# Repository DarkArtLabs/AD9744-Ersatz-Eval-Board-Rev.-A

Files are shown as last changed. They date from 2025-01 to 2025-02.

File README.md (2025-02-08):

# AD9744 Ersatz Eval Board
A low-cost evaluation board for the Analog Devices [AD9744](https://www.analog.com/en/products/ad9744.html) 14-bit DAC.

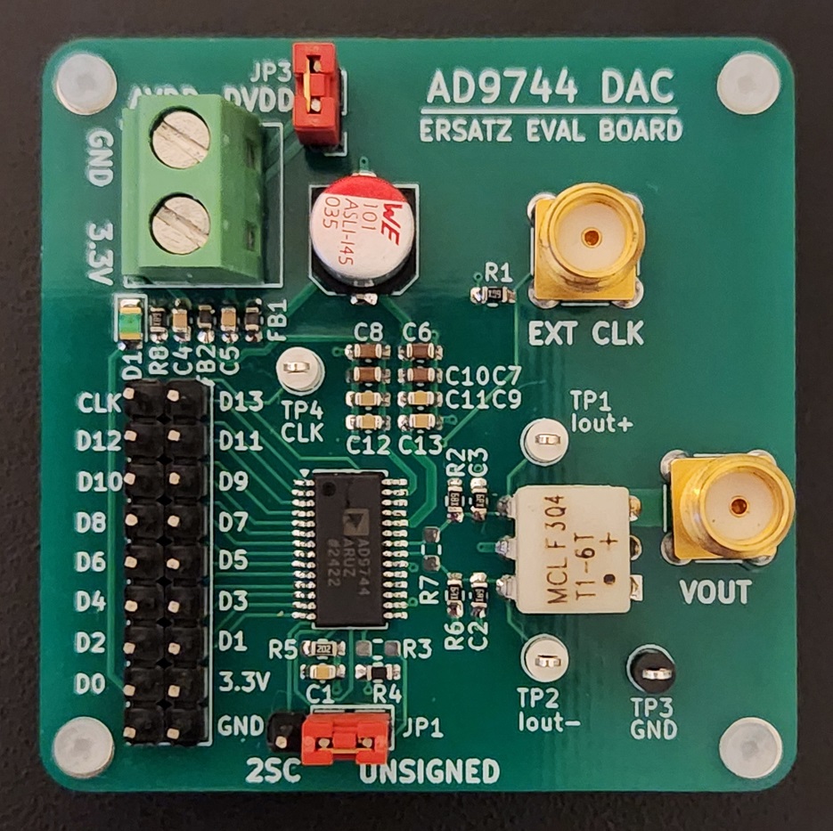
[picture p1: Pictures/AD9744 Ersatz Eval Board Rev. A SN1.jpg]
SN1


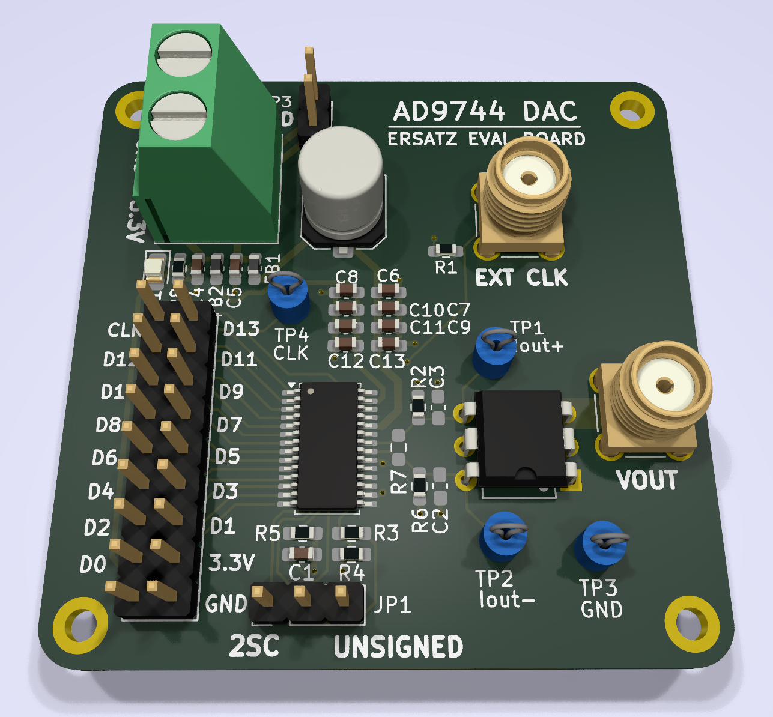
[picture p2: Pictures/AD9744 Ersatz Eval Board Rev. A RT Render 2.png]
3D Render Front


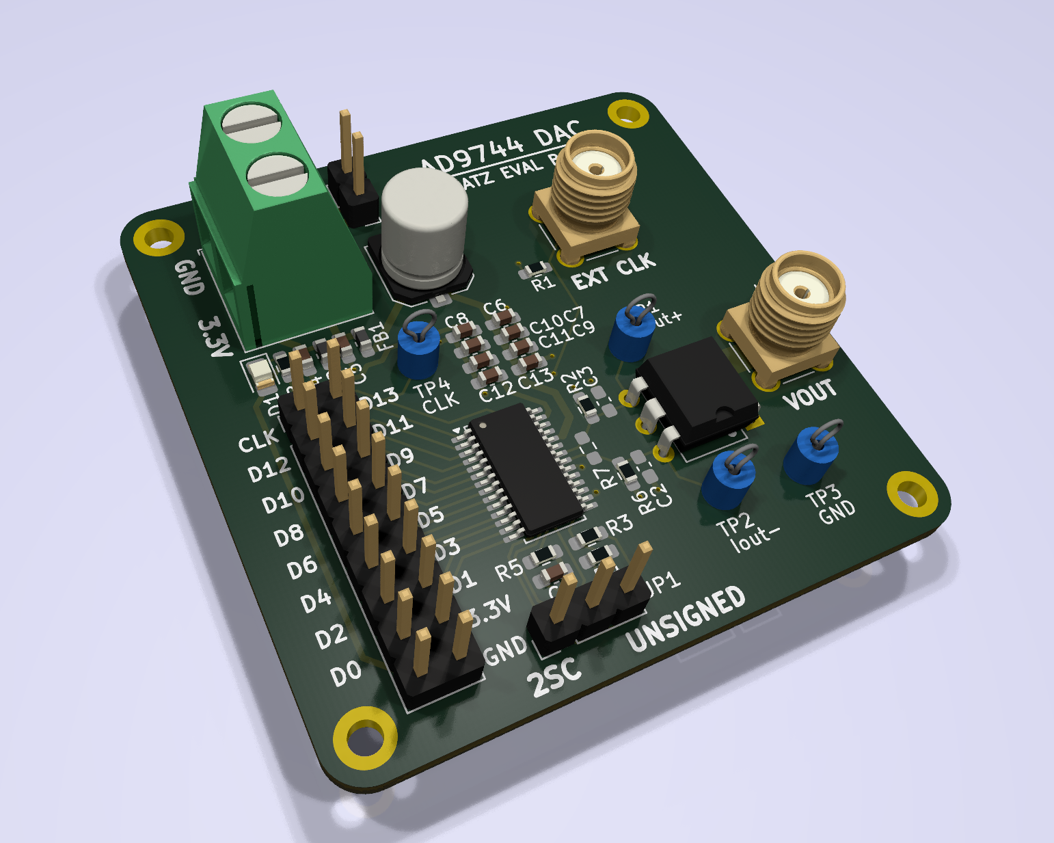
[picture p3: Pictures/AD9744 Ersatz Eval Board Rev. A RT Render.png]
3D Render 2


The ersatz evaluation board is a low-cost alternative to the AD9744-FMC-EBZ evaluation board produced by Analog Devices which retails for approximately $500. The full BOM cost for this project including components, the board itself, tax, and shipping is about $100. 
The area of the PCB is 23 cm<sup>2</sup> and it is designed to be built on standard 2-layer FR4 by any PCB fabricator. All components sit on the top of the board and the design is hand-solderable. 

# Features
  - Power the board through pin header, terminal block, or separately power analog and digital sections
  - Select 2's complement or unsigned binary DAC word using a jumper
  - External clock input
  - 50 Ohm output impedance
  - Test points on DAC output before balun
  - Mounting holes for M2 hardware or standoffs

# What's Included
Downloads are available below for those who wish to make their own ersatz eval board. The KiCAD project files are also available for those who wish to modify the design. 

## Schematic
The schematic may also be viewed above in the Documents directory.

## Bill of Materials
The BOM may also be viewed above in the Documents directory. It contains manufacturer part numbers and quantities for every component. It also contains Mouser part numbers for easy cross reference. The BOM may be uploaded to the Mouser website and a shopping cart with correct quantities will automatically be generated. Parts may be substituted as long as they meet the minimum tolerances and footprint dimensions. 

To open this file with Excel, it is recommended to import the CSV data. Simply opening the file with Excel will cause formatting errors. 

## Gerbers, Drill File, Drill Map
These files have been generated according to the specifications that JLCPCB requires, but they will likely work at other fabricators such as PCBWay or OSHPARK.

## User Guide
The user guide may also be viewed above in the Documents directory. It contains information on assembly, I/O ports, and jumper options.

# Performance Characteristics

## Power Dissapation

For AVDD and DVDD rails tied together. Test conditions: $` f_{out} = 26.25 \ [MHz] `$, $` f_{clk} = 210 \ [MHz] `$

<br/>

$$ V_{DD} = 3.3 \ \ [V] $$

$$ I_{DD} = 65 \ \ [mA] $$

$$ P_{diss} = 215 \ \ [mW] $$

## S-Parameters & Return Loss

Vout S11: 10 MHz - 100 MHz 
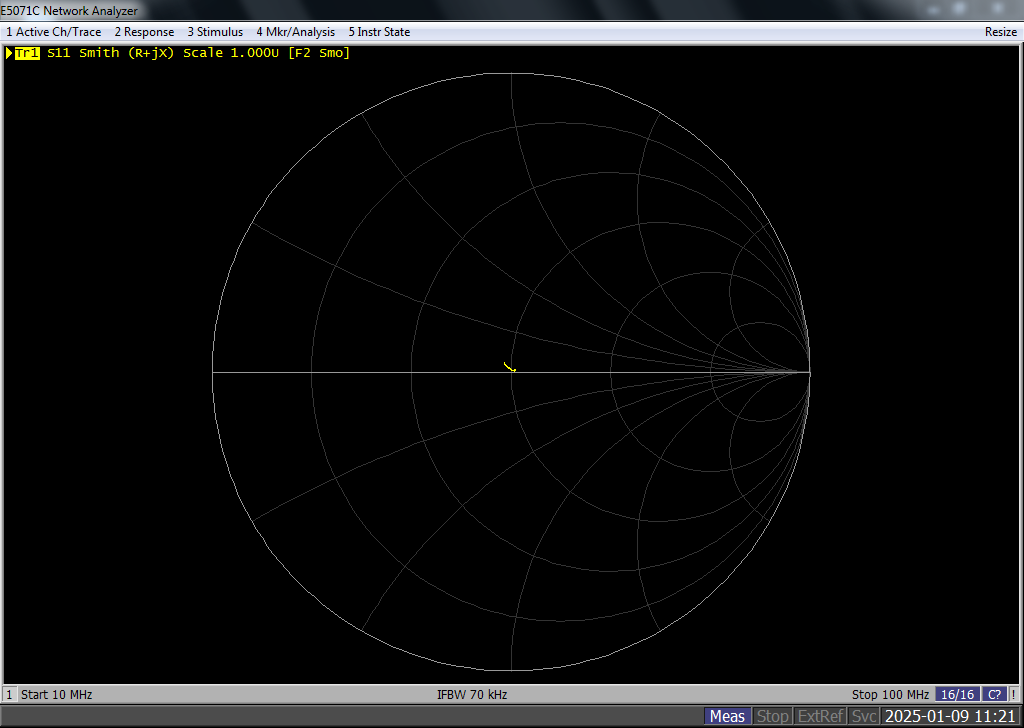
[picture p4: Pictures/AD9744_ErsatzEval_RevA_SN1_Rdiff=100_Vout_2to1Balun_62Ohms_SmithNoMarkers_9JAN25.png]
S11 Smith No Markers


Vout S11: 10 MHz - 100 MHz (markers every 10 MHz)
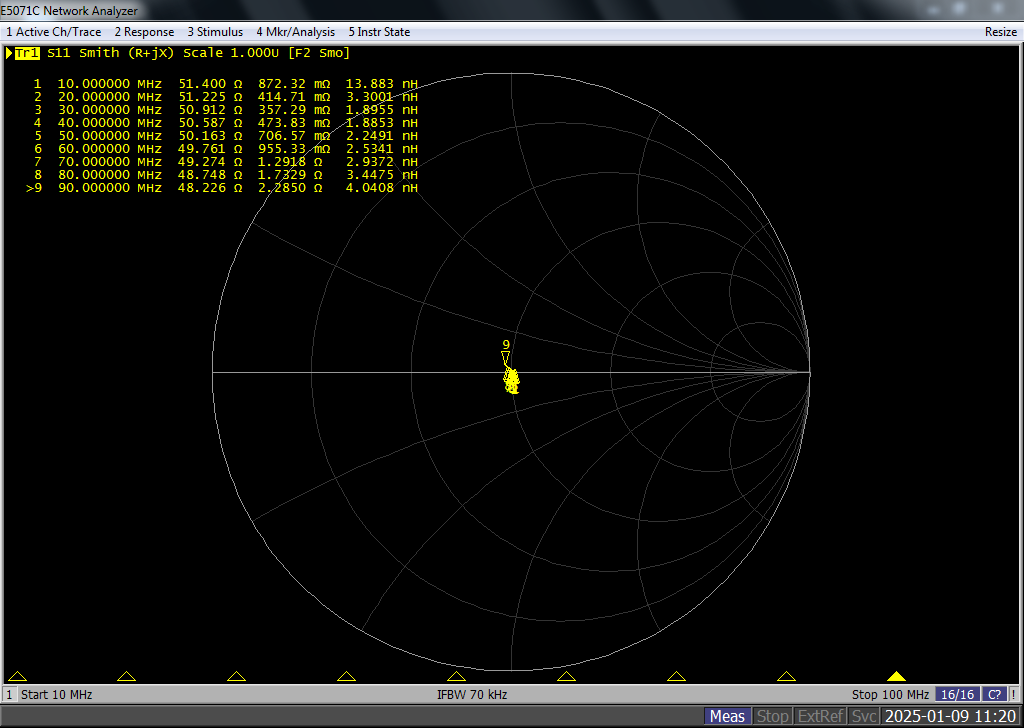
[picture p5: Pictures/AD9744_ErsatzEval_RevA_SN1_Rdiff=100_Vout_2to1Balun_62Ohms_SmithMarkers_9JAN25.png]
S11 Smith Markers


Vout Return Loss: 10 MHz - 100 MHz (markers every 10 MHz)
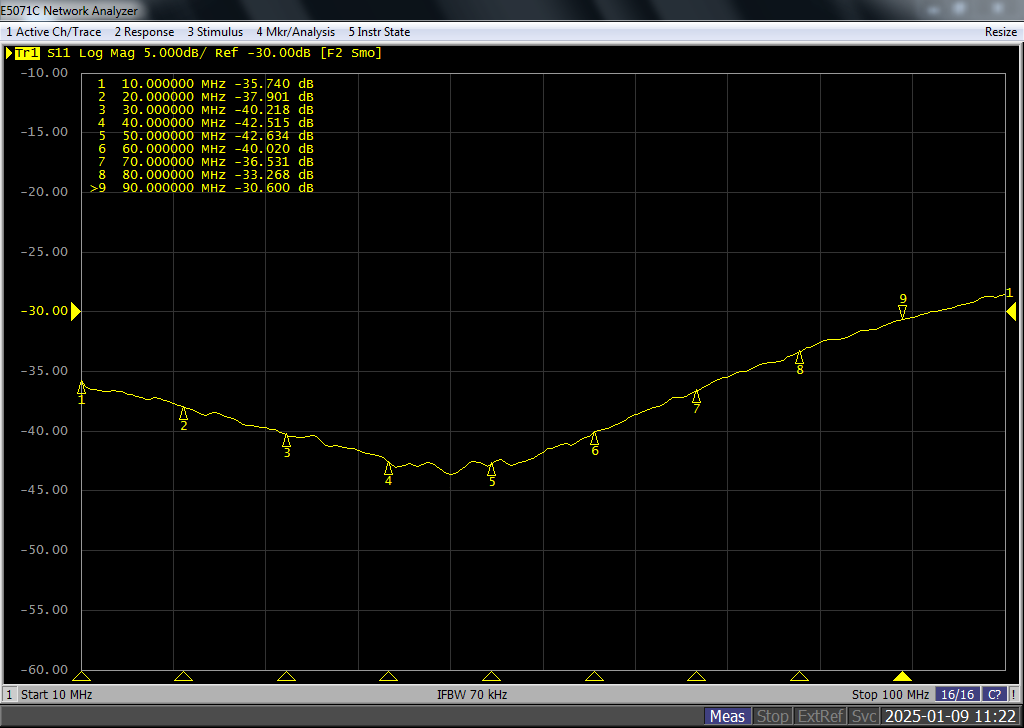
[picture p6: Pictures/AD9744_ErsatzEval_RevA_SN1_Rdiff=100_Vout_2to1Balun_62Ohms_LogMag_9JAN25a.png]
S11 Log Magnitude Markers

  
## Output Power

26.25 MHz Single Tone (210 MSPS): 0 dBm
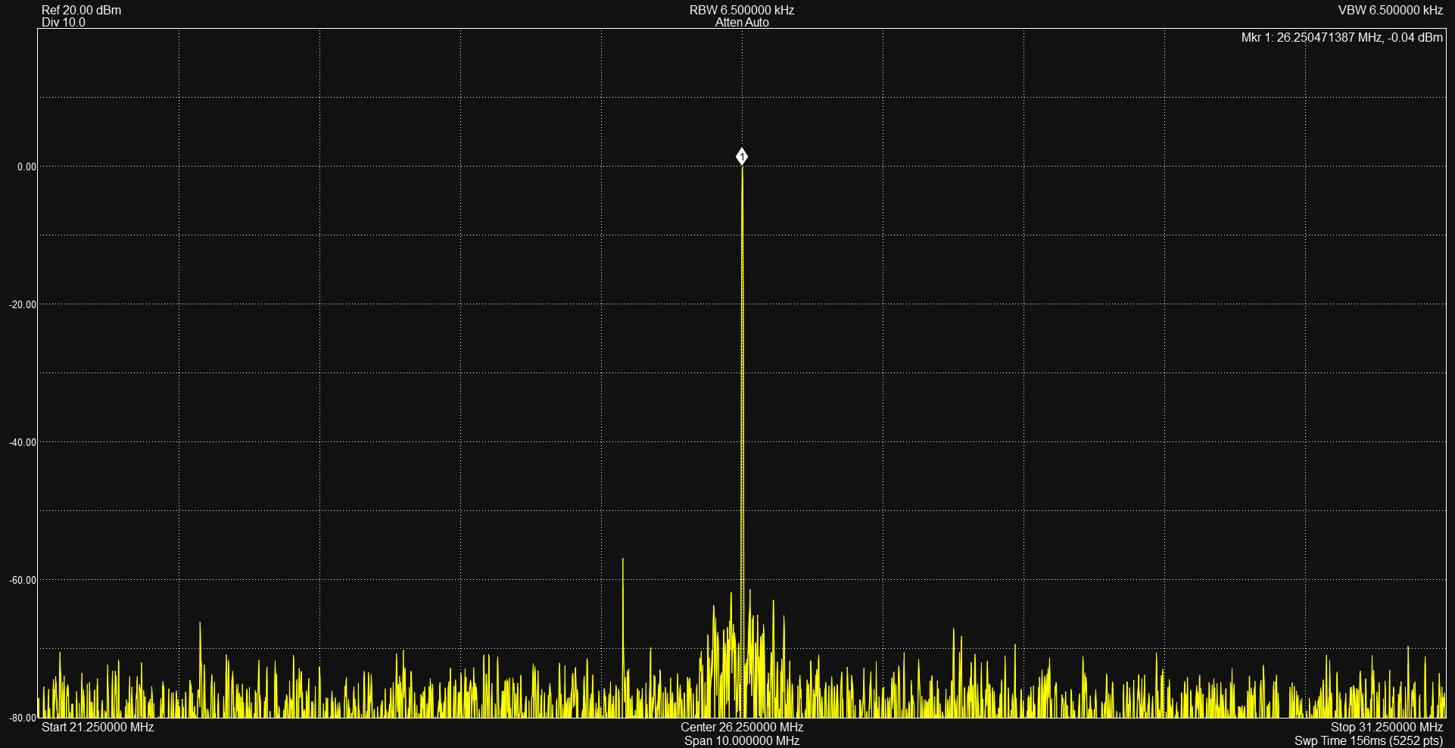
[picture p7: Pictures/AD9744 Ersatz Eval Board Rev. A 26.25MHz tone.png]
Single 26.25 MHz tone


# Downloads

Schematic: AD9744 Ersatz Eval Board Rev. A Schematic.pdf

Gerbers: AD9744 Ersatz Eval Board Rev. A Gerbers.zip

BOM: AD9744 Ersatz Eval Board Rev. A BOM.csv

User Guide: AD9744 Ersatz Eval Board Rev. A User Guide.pdf

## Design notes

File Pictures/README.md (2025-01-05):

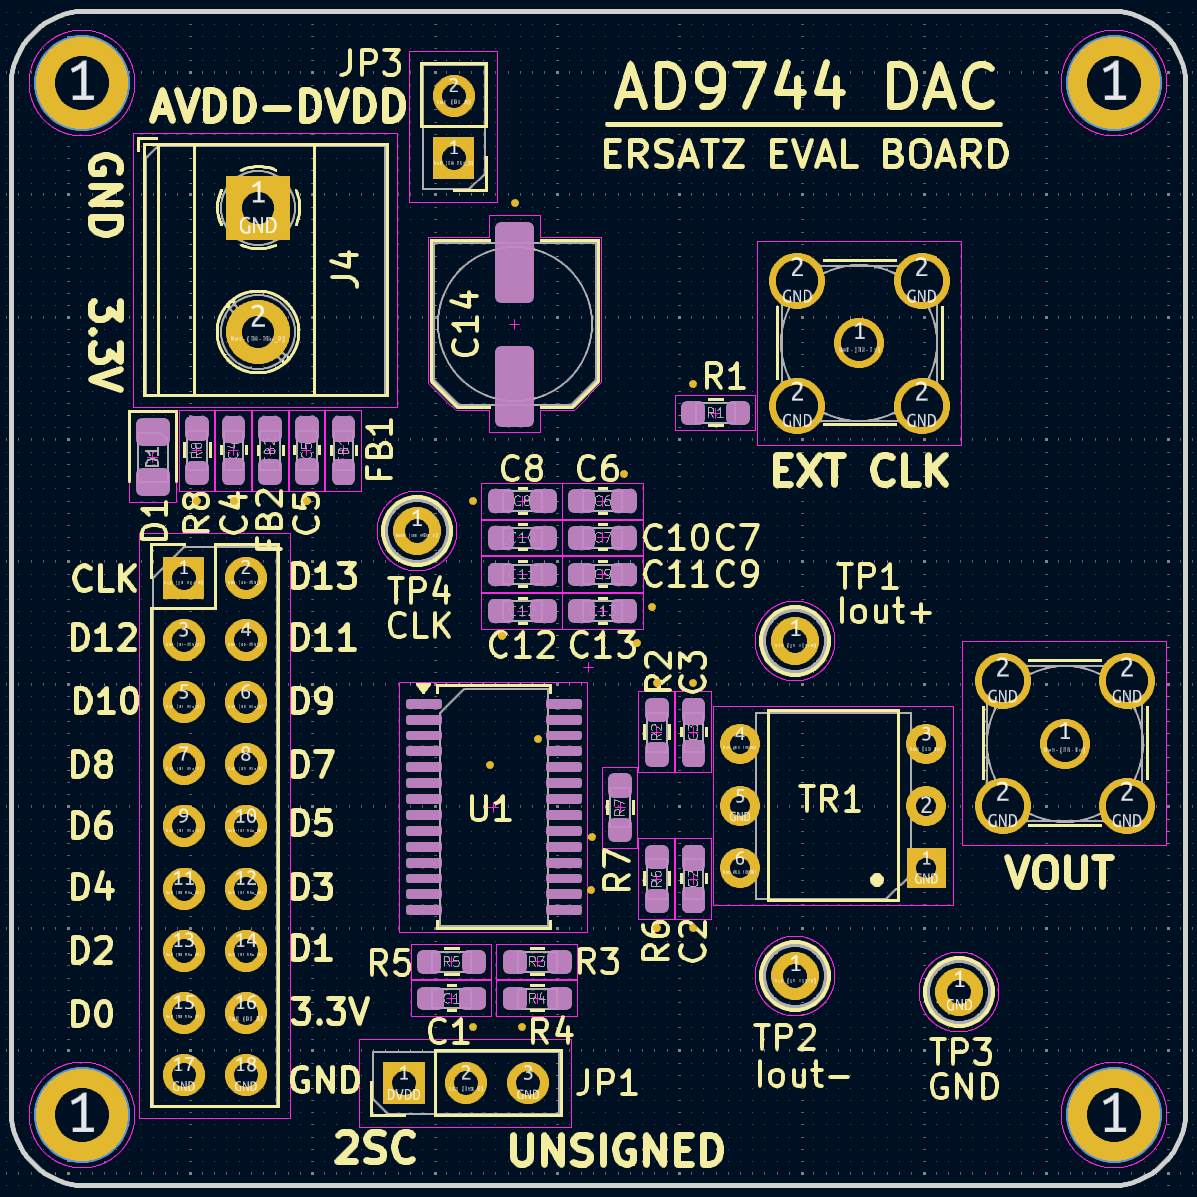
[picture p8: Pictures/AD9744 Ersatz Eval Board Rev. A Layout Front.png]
Layout Front


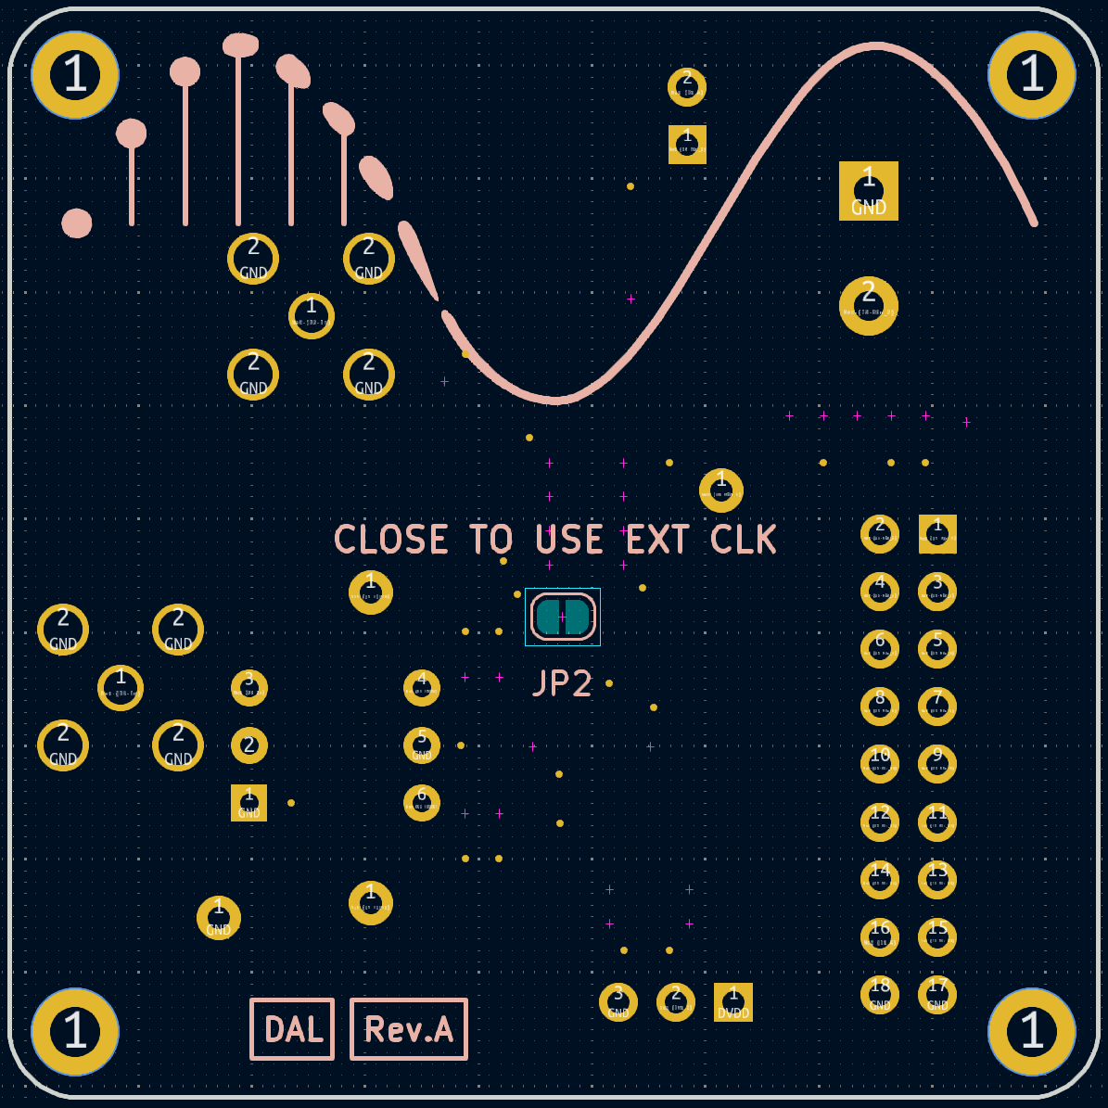
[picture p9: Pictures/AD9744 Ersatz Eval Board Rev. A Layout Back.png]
Layout Back


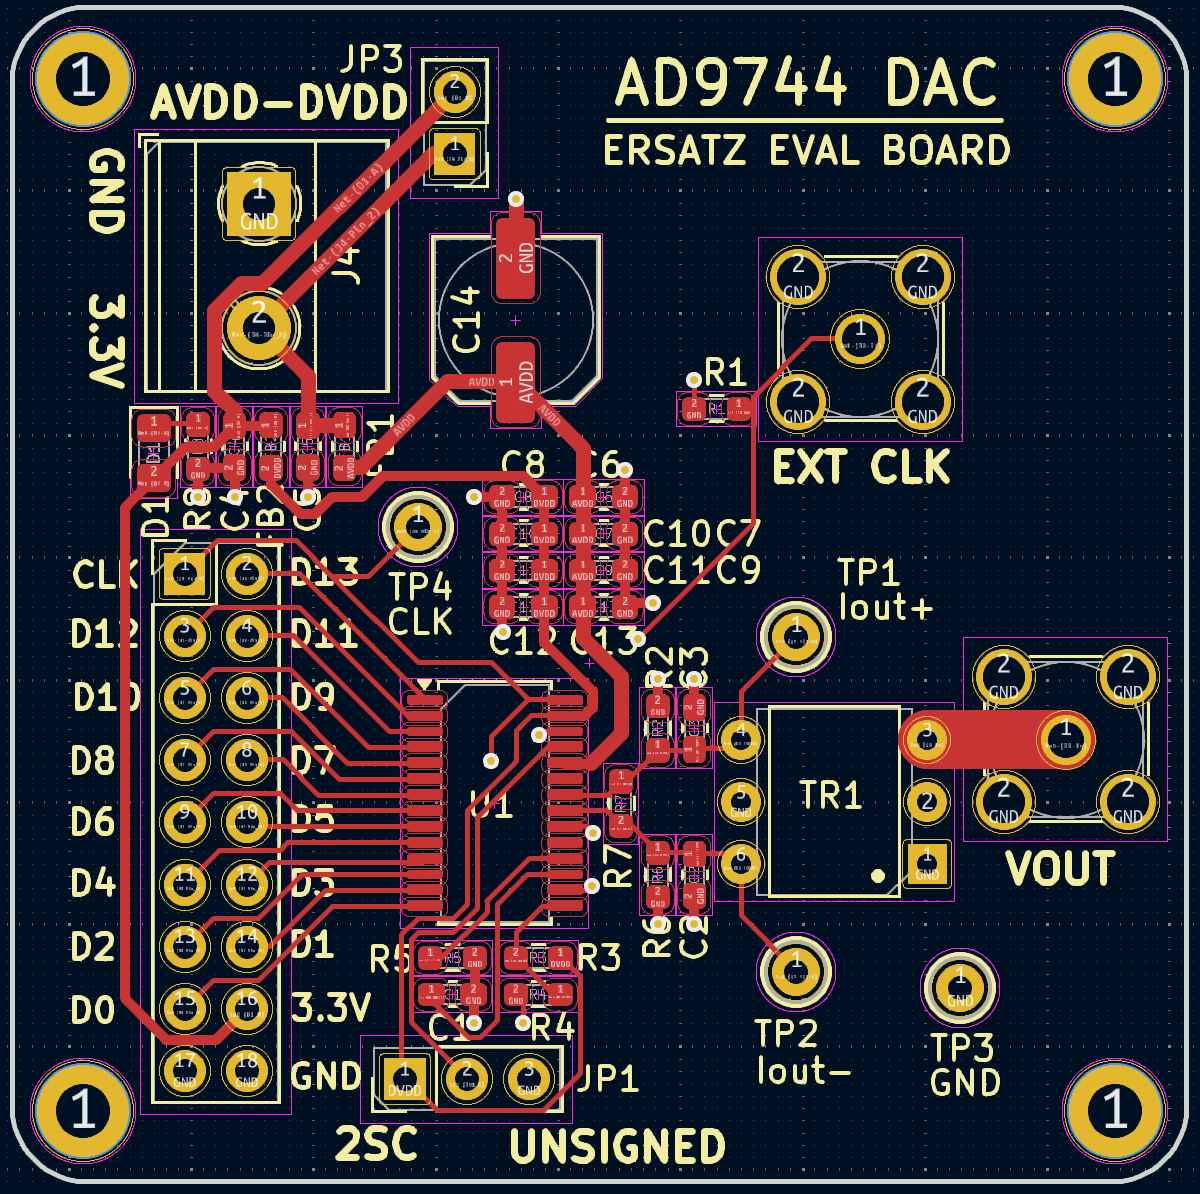
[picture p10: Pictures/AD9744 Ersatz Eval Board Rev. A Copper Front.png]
Copper Front


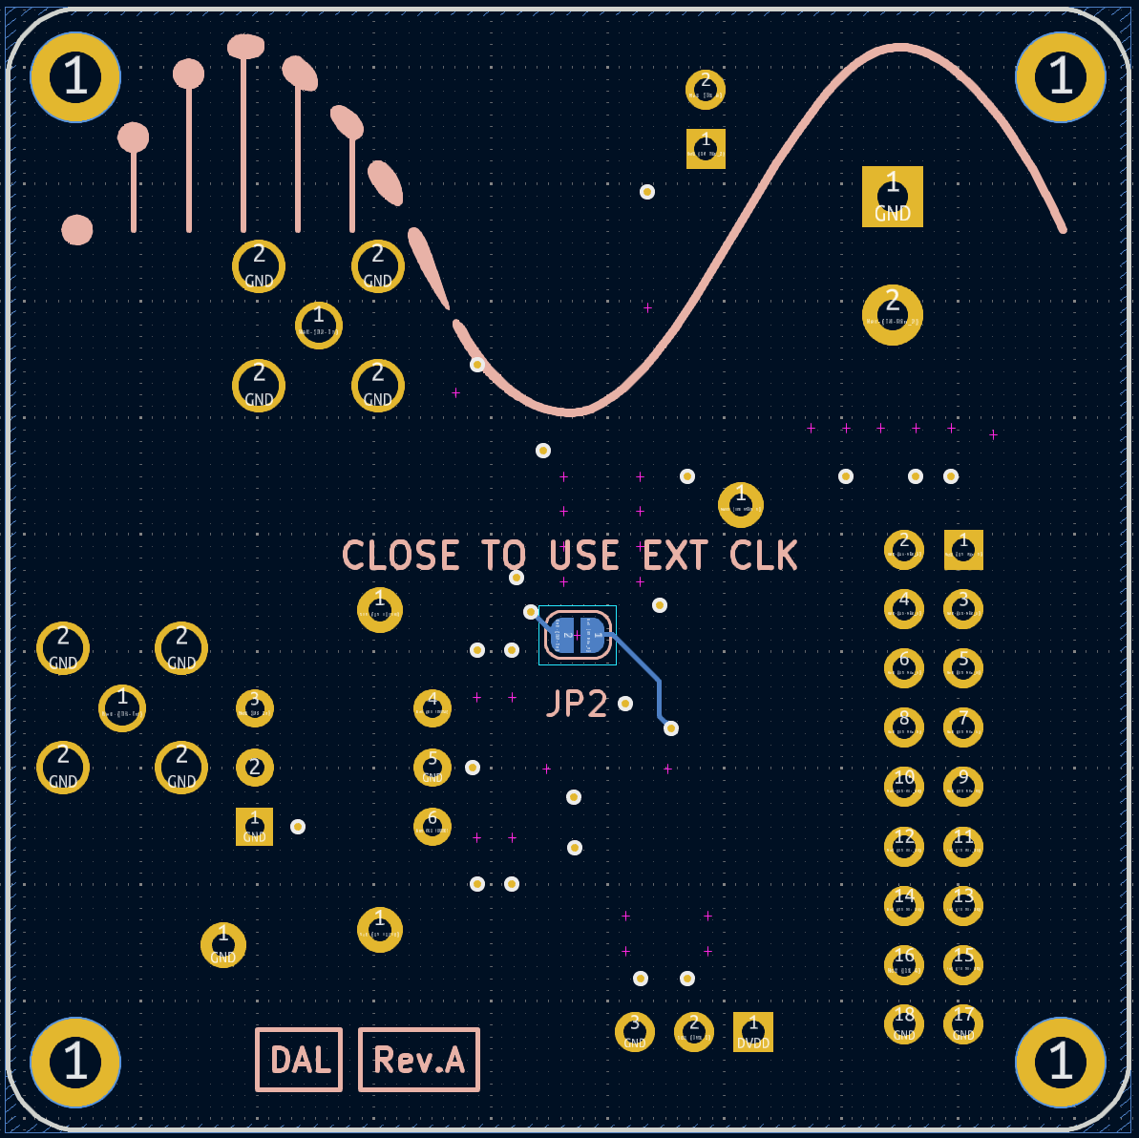
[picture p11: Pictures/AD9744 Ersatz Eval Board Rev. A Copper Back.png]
Copper Back


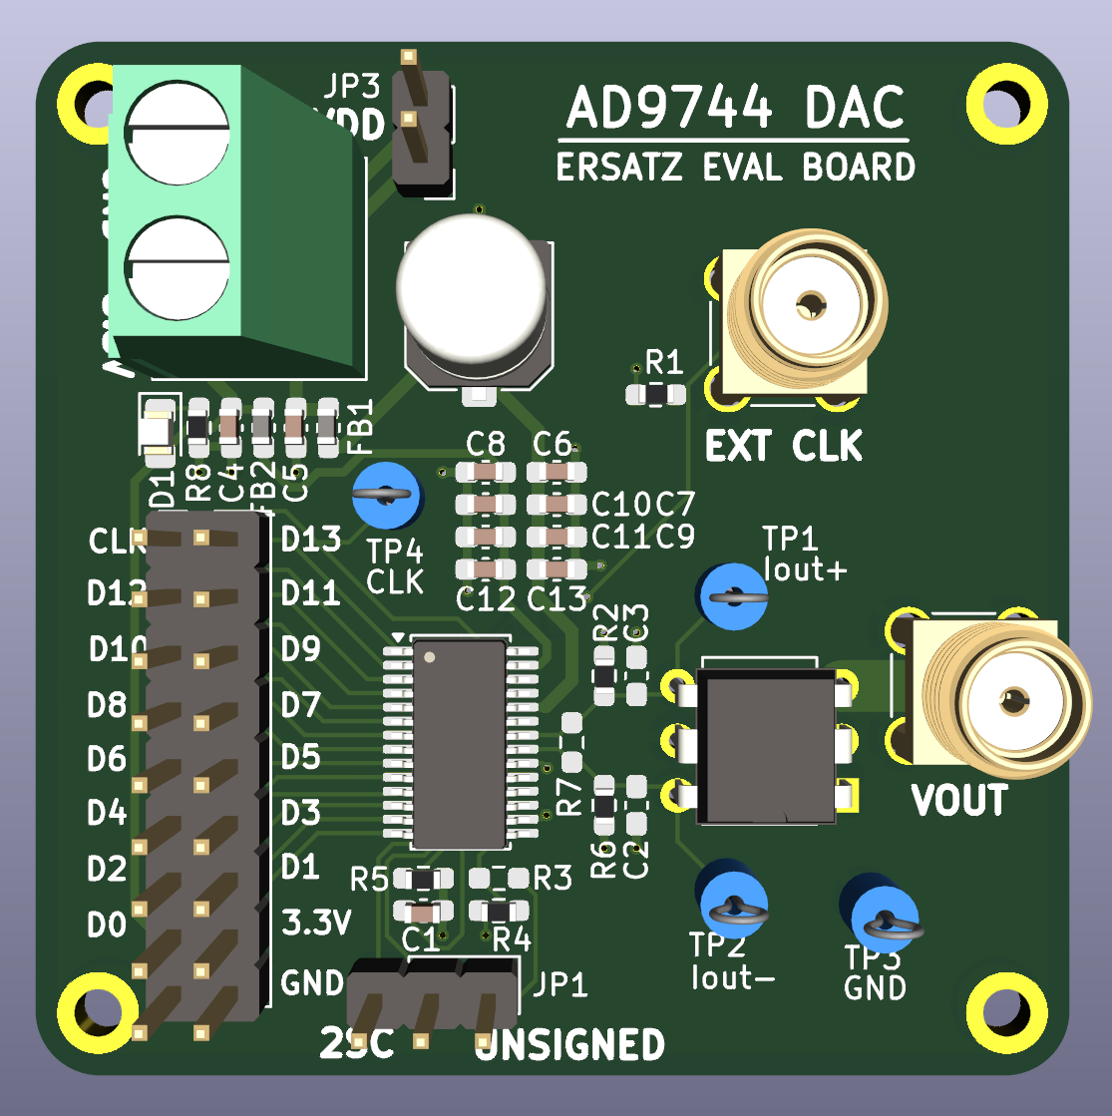
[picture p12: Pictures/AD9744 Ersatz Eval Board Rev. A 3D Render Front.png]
3D Render Front


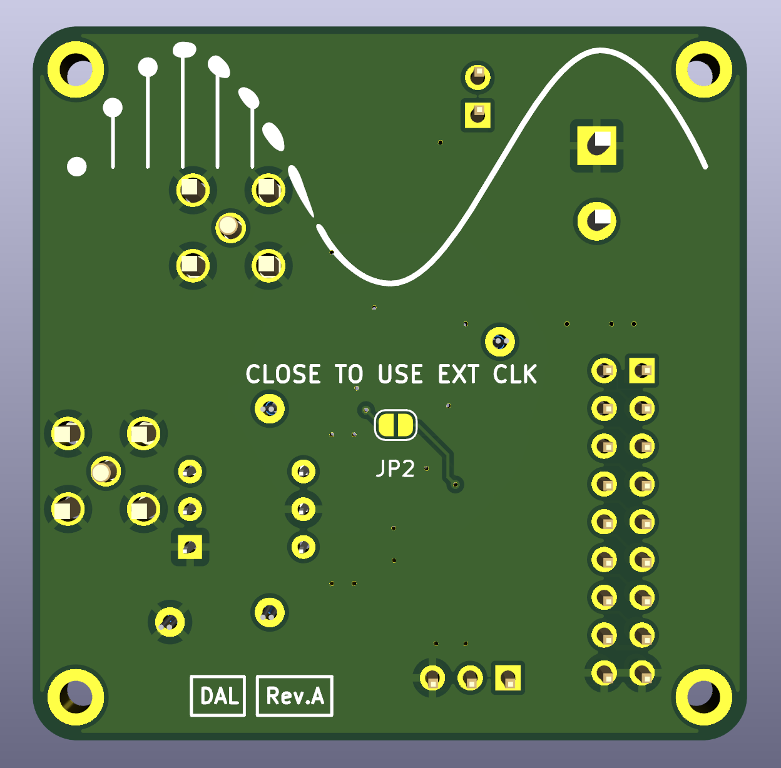
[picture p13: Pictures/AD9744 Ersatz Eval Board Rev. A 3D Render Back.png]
3D Render Back


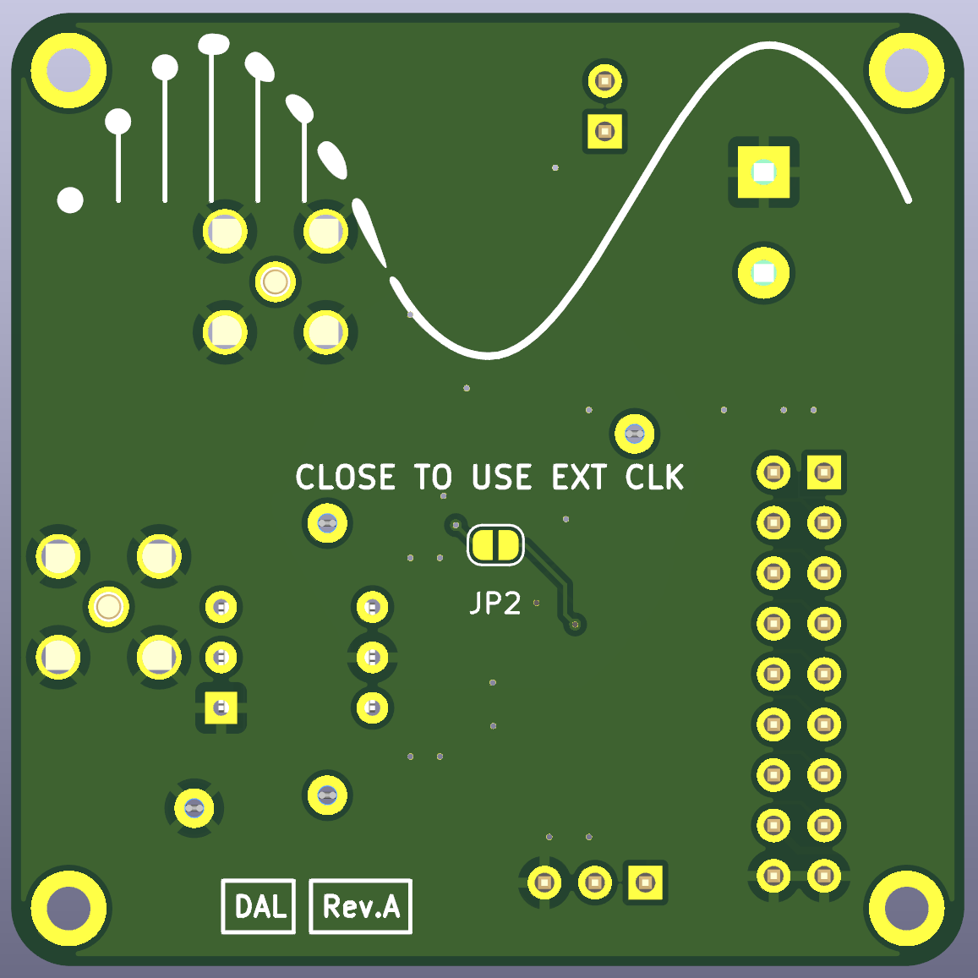
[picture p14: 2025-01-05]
Pictures/AD9744 Ersatz Eval Board Rev. A Orthographic Back.png

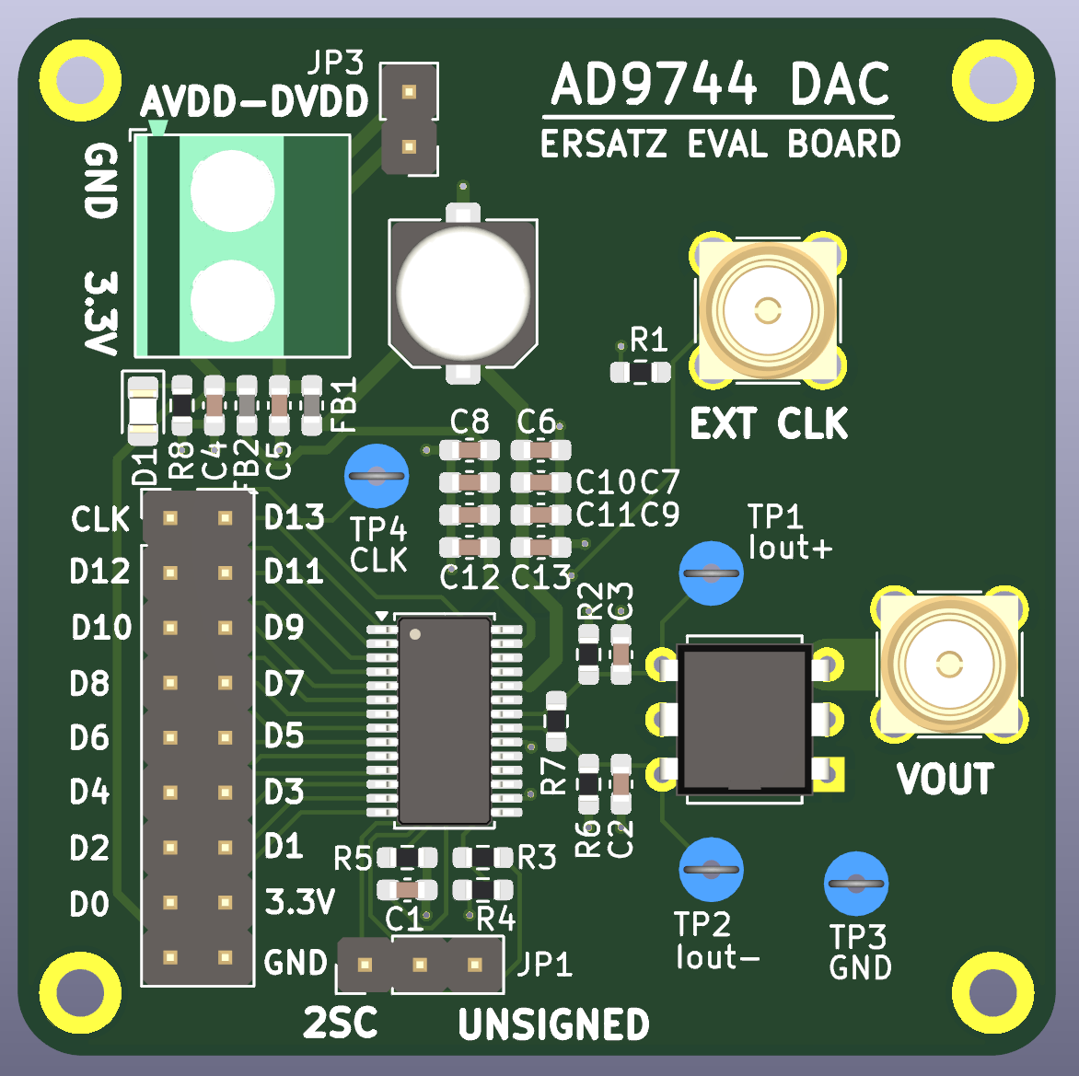
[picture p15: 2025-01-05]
Pictures/AD9744 Ersatz Eval Board Rev. A Orthographic Front.png

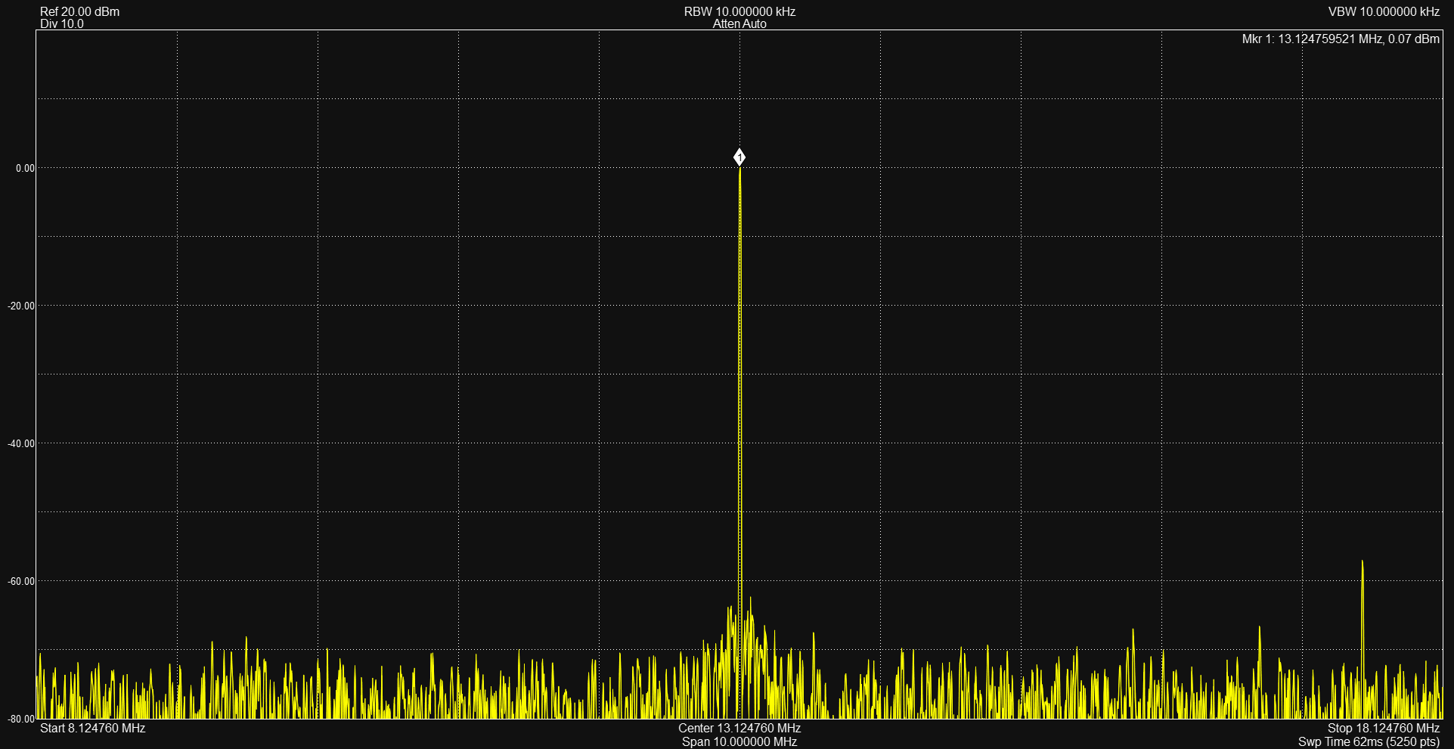
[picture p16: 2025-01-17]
Pictures/AD9744 Ersatz Eval Board Rev. A 13.12MHz tone.png

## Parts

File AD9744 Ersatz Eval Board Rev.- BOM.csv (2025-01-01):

Item # | Qty | Ref Des | Manufacturer | Manufacturer Part Number | Description | Package | Type | Location
1 | 1 | U1 | Analog Devices | AD9744ARUZRL7 | 14 Bit DAC; 210 MSPS | TSSOP-28 | SMT | Top
2 | 1 | TR1 | Mini Circuits | T1-6T+ | Balun; 1:1 | W38 | SMT | Top
3 | 1 | J1 | Adam Tech | PH2-18-UA | Pin Header; 2.54mm pitch; 2x9; Male |  | Thru-Hole | Top
4 | 1 | JP1 | Adam Tech | PH1-03-UA | Pin Header; 2.54mm pitch; 1x3; Male |  | Thru-Hole | Top
5 | 1 | JP3 | Adam Tech | PH1-02-UA | Pin Header; 2.54mm pitch; 1x2; Male |  | Thru-Hole | Top
6 | 2 | J2, J3 | Amphenol | 901-144 | SMA Connector; Female; Vertical; 5.08 pitch |  | Thru-Hole | Top
7 | 1 | J4 | Keystone | 8738 | 2 Pos Terminal Block; Screw Type; 5.08mm pitch; Blue |  | Thru-Hole | Top
8 | 1 | D1 | Wurth | 150224BS73100 | Blue LED | 0805 | SMT | Top
9 | 2 | FB1, FB2 | Murata | BLM18KN601EH1D | Ferrite Bead | 0603 | SMT | Top
10 | 1 | C14 | Wurth | 865080545012 | Electrolytic Capacitor; 100uF; 35VDC | 6.3mm | SMT | Top
11 | 2 | C7, C10 | Kyocera | 0603YD106MAT2A | MLCC 10uF; 16VDC; X5R | 0603 | SMT | Top
12 | 2 | C6, C8 | Murata | GRM188R61E106KA73J | MLCC 10uF; 25VDC; X5R | 0603 | SMT | Top
13 | 7 | C1, C4, C5, C9, C11, C12, C13 | Kyocera | KAM15AR71C104KM | MLCC; 0.1uF; 16VDC; X7R | 0603 | SMT | Top
14 | 4 | R1, R2, R6 | Yageo | AT0603DRD0749R9L | 50 Ohm; 1% | 0603 | SMT | Top
15 | 1 | R5 | Panasonic | ERA-3AED202V | 2k Ohm; 1% | 0603 | SMT | Top
16 | 1 | R4 | Vishay | CRCW060310K0FKEI | 10k Ohm; 5% | 0603 | SMT | Top
17 | 1 | R8 | Vishay | CRCW060313R0JNEA | 13 Ohm, 5% | 0603 | SMT | Top
18 | 3 | TP1, TP2, TP4 | Keystone | 5002 | Mini Loop Test Point; White |  | Thru-Hole | Top
19 | 1 | TP3 | Keystone | 5001 | Mini Loop Test Point; Black |  | Thru-Hole | Top

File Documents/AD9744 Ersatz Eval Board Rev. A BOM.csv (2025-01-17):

Item # | Qty | Ref Des | Manufacturer | Manufacturer Part Number | Mouser Part Number | Description | Package | Type | Location | Note
1 | 1 | U1 | Analog Devices | AD9744ARUZRL7 | 584-AD9744ARUZR7 | 14 Bit DAC, 210 MSPS | TSSOP-28 | SMT | Top
2 | 1 | TR1 | Mini Circuits | T2-1T+ | 139-T2-1T+ | Balun, 2:1 Impedance Ratio | W38 | SMT | Top | Must bend legs
3 | 1 | J1 | Adam Tech | PH2-18-UA | 737-PH2-18-UA | Pin Header, 2.54mm pitch, 2x9; Male |  | Thru-Hole | Top
4 | 1 | JP1 | Adam Tech | PH1-03-UA | 737-PH1-03-UA | Pin Header, 2.54mm pitch; 1x3, Male |  | Thru-Hole | Top
5 | 1 | JP3 | Adam Tech | PH1-02-UA | 737-PH1-02-UA | Pin Header, 2.54mm pitch, 1x2, Male |  | Thru-Hole | Top
6 | 2 | J2, J3 | Amphenol | 901-144 | 523-901-144 | SMA Connector, Female, Vertical, 5.08 pitch |  | Thru-Hole | Top
7 | 1 | J4 | Phoenix Contact | 1729128 | 651-1729128 | 2 Pos Terminal Block, Screw Type, 5.08mm pitch, Green |  | Thru-Hole | Top
8 | 1 | D1 | Kingbright | AP2012SGD3 | 604-AP2012SGD3 | LED, Green | 0805 | SMT | Top
9 | 2 | FB1, FB2 | Murata | BLM18KN601EH1D | 81-BLM18KN601EH1D | Ferrite Bead | 0603 | SMT | Top
10 | 1 | C14 | Wurth | 865080545012 | 710-865080545012 | Electrolytic Capacitor, 100uF, 35VDC | 6.3mm | SMT | Top
11 | 2 | C7, C10 | Kyocera | 0603YD106MAT2A | 581-0603YD106MAT2A | MLCC, 10uF, 16VDC, X5R | 0603 | SMT | Top
12 | 2 | C6, C8 | Murata | GRM188R61E106KA73J | 81-GRM188R61E106KA3J | MLCC, 10uF, 25VDC, X5R | 0603 | SMT | Top
13 | 7 | C1, C4, C5, C9, C11, C12, C13 | Kyocera | KAM15AR71C104KM | 581-KAM15AR71C104KM | MLCC, 0.1uF, 16VDC, X7R | 0603 | SMT | Top
14 | 2 | R1, R8 | Yageo | AT0603DRD0749R9L | 603-AT0603DRD0749R9L | 50 Ohm, 1% | 0603 | SMT | Top
15 | 2 | R2, R6 | Vishay | MCT06030C6209FP500 | 594-MCT06030C6209FP5 | 62 Ohm, 1% | 0603 | SMT | Top
16 | 1 | R5 | Panasonic | ERA-3AED2371V | 667-ERA-3AED2371V | 2.37k Ohm, 0.5%, 25 PPM/C | 0603 | SMT | Top
17 | 1 | R4 | Vishay | CRCW060310K0FKEI | 71-CRCW060310K0FKEI | 10k Ohm, 5% | 0603 | SMT | Top
18 | 3 | TP1, TP2, TP4 | Keystone | 5002 | 534-5002 | Mini Loop Test Point, White |  | Thru-Hole | Top
19 | 1 | TP3 | Keystone | 5001 | 534-5001 | Mini Loop Test Point, Black |  | Thru-Hole | Top

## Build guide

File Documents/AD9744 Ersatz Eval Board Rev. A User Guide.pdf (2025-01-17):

# AD9744 Ersatz Eval Board User Guide

## Assembly

The ersatz eval board is able to be soldered by hand. The footprints of many components have been extended to make the soldering process easier. It is recommended to follow the general guidelines below when soldering components to the board.

Place and solder U1 (AD9744)

Orient pin 1 up and to the left (toward the terminal block)

Place and solder all 0603 and 0805 size components (resistors, capacitors, LED)

Point LED cathode up toward terminal block

Place and solder C14 (100uF electrolytic)

Positive terminal oriented downwards toward U1

Place and solder TR1 (T2-1T+)

Orient pin 1 down and to the right (toward TP3)

Place and solder all through-hole components (pin headers, terminal block, test points, SMA connectors)

Attach M2 size standoffs or mounting hardware (optional, recommended)

## Interfaces

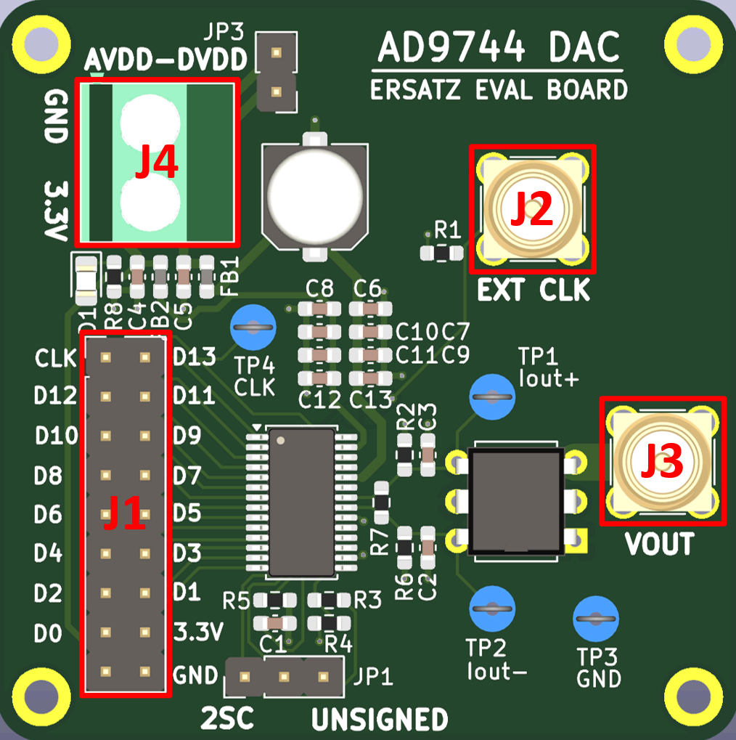
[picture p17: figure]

Interface Diagram

Digital input to the DAC. The CLK pin is the default clock input. The 3.3V pin supplies the digital section.

Optional external clock input to the DAC. The port accepts a CMOS-level signal. JP2 must be closed to use this port.

Analog output of the DAC. It is impedance matched to 50 Ohms.

The 3.3V input to the analog section.

J1 - 2x9 Digital Input J2 - External Clock Input J3 - Analog Voltage Output J4 - 3.3V AVDD Terminal Block

## Jumpers

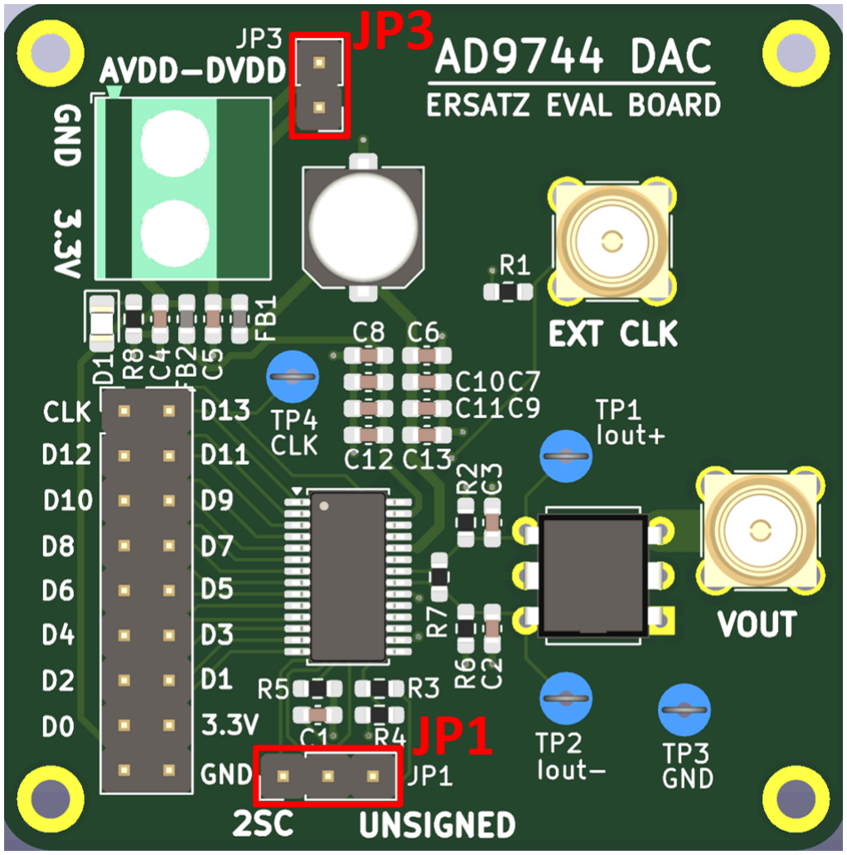
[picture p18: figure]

Jumper Diagram Front

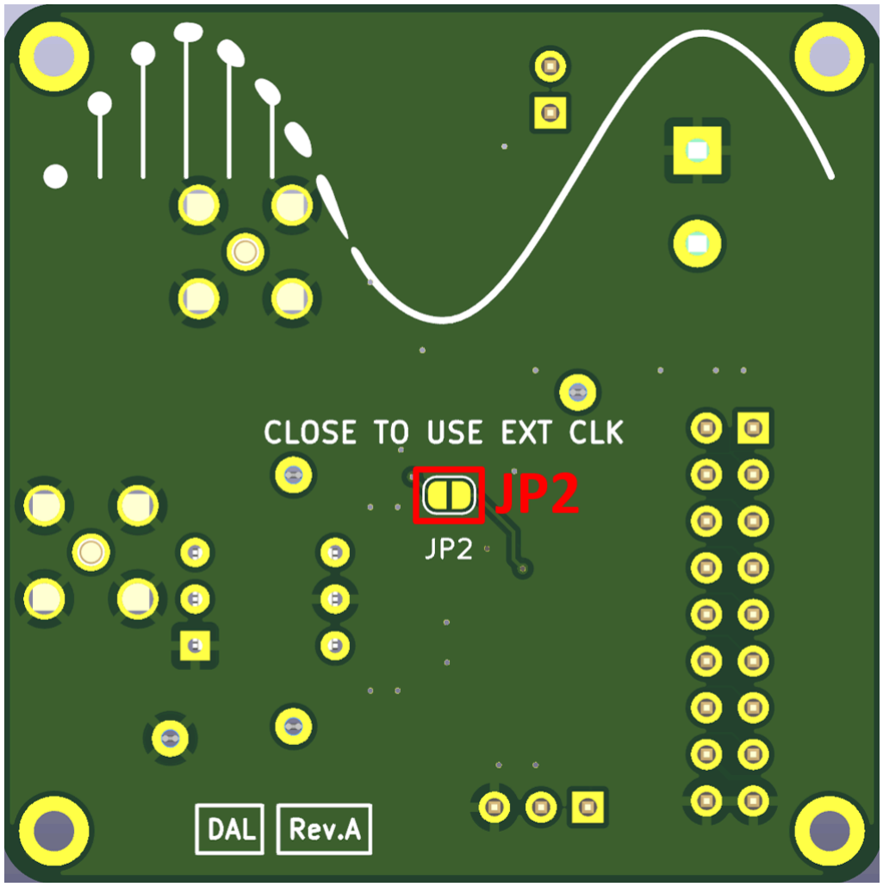
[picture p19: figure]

Jumper Diagram Back

Allows the selection of either 2’s complement or unsigned binary DAC words to be written to the AD9744. Place a jumper on the right two pins to select unsigned binary and the left two pins to select 2’s complement.

Allows the use of the external clock port J2. Close this jumper to enable the port. Located on rear of the board.

Leave this jumper open if supplying a clock through pin header J1.

Placing a jumper on this header ties AVDD and DVDD together. This allows the user to power the ersatz eval board through the 3.3V pin on J1. Alternately, the 3.3V pin may be disconnected and the board powered through the terminal block.

Removing the jumper on JP3 allows for the digital section to be powered through the 3.3V pin on header J1 and the analog section to be powered through the terminal block.

## Test Points

Test point is connected to the DAC differential output IoutA (non-inverting output) immediately before the balun. This allows for DC voltages and slow signals (f<15kHz) to be measured as they will not pass through the balun. This test point should measure full scale output for a full-scale DAC word (0x3FFF).

Test point is connected to the DAC differential output IoutB (inverting output) immediately before the balun. This allows for DC voltages and slow signals (f<15kHz) to be measured as they will not pass through the balun. This test point should measure full scale output for a min-scale DAC word (0x0000).

Test point is connected to ground.

Test point is connected to the clock input.

## JP1 - DAC Word Format

## JP2 - External Clock Enable JP3 - Analog and Digital Voltage Rail Selection

## TP1 - Iout+ TP2 - Iout-

## TP3 - Ground TP4 - CLK

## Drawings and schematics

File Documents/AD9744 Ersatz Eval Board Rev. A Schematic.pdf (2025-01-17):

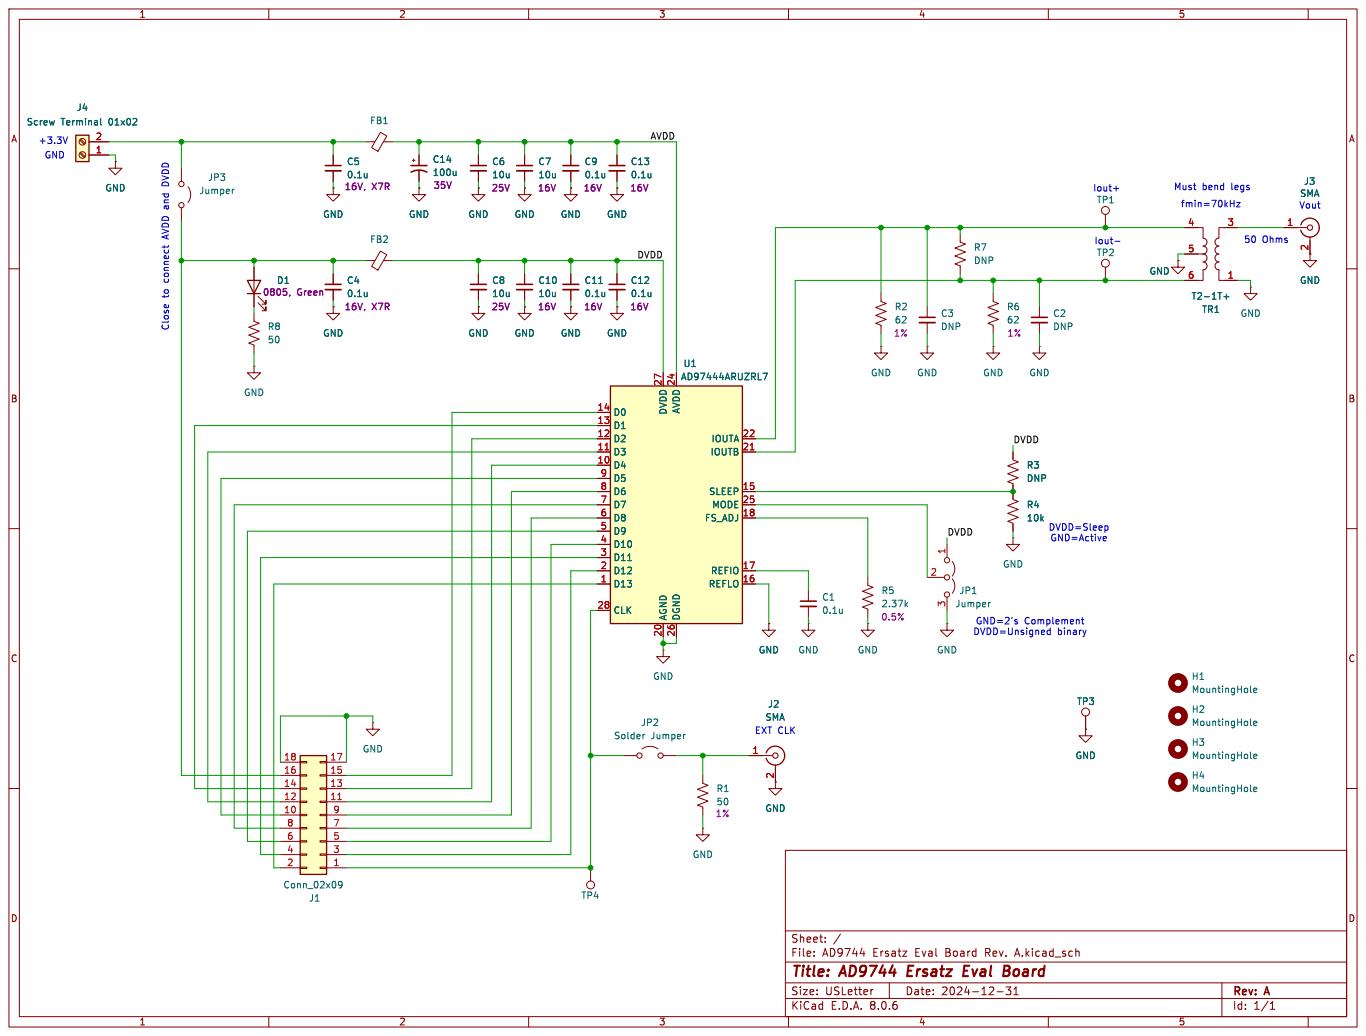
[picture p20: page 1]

EXT CLK Close to connect AVDD and DVDD

Id: 1/1 Title: AD9744 Ersatz Eval Board

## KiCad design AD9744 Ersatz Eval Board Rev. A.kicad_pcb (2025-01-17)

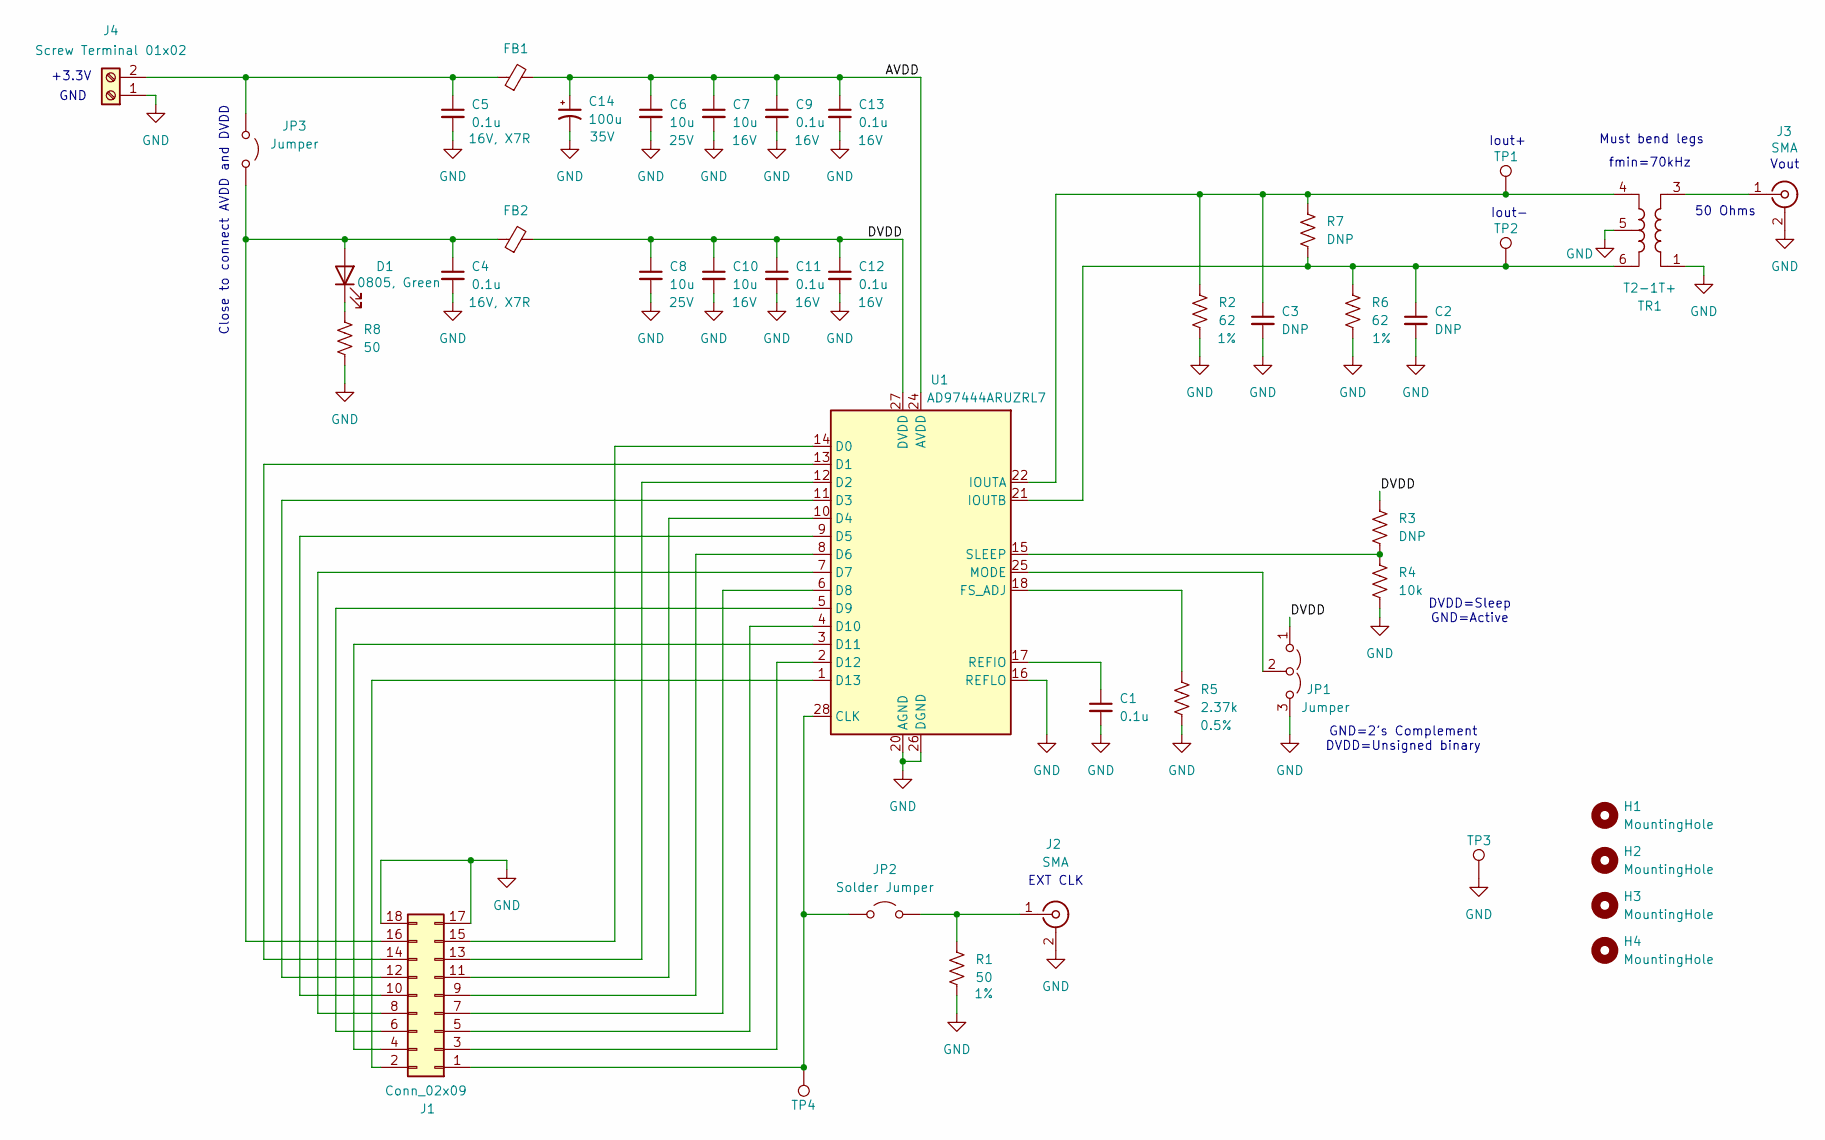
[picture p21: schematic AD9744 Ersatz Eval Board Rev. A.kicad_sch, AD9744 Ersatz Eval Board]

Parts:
C1, C4, C5, C9, C11, C12, C13: 0.1u; C_0603_1608Metric_Pad1.08x0.95mm_HandSolder
C2, C3: DNP; C_0603_1608Metric_Pad1.08x0.95mm_HandSolder
C6, C7, C8, C10: 10u; C_0603_1608Metric_Pad1.08x0.95mm_HandSolder
C14: 100u; C_Elec_6.3x7.7
D1: AP2012SGD3; LED_0805_2012Metric_Pad1.15x1.40mm_HandSolder
FB1, FB2: BLM18KN601EH1D; L_0603_1608Metric_Pad1.05x0.95mm_HandSolder
H1, H2, H3, H4: MountingHole; MountingHole_2.2mm_M2_DIN965_Pad
J1: Conn_02x09; PinHeader_2x09_P2.54mm_Vertical
J2, J3: SMA; SMA_Amphenol_901-144_Vertical
J4: Screw Terminal 01x02; TerminalBlock_Phoenix_MKDS-1,5-2-5.08_1x02_P5.08mm_Horizont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
JP1: Jumper; PinHeader_1x03_P2.54mm_Vertical
JP2: Solder Jumper; SolderJumper-2_P1.3mm_Open_RoundedPad1.0x1.5mm
JP3: Jumper; PinHeader_1x02_P2.54mm_Vertical
R1, R8: 50; R_0603_1608Metric_Pad0.98x0.95mm_HandSolder
R2, R6: 62; R_0603_1608Metric_Pad0.98x0.95mm_HandSolder
R3, R7: DNP; R_0603_1608Metric_Pad0.98x0.95mm_HandSolder
R4: 10k; R_0603_1608Metric_Pad0.98x0.95mm_HandSolder
R5: 2.37k; R_0603_1608Metric_Pad0.98x0.95mm_HandSolder
TP1, TP2, TP3, TP4: TestPoint_Keystone_5000-5004_Miniature
TR1: T2-1T+; DIP-6_W7.62mm
U1: AD97444ARUZRL7; TSSOP-28_4.4x9.7mm_P0.65mm

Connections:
/AVDD: C6.1, C7.1, C9.1, C13.1, C14.1, FB1.2, U1.24 (AVDD)
/DVDD: C8.1, C10.1, C11.1, C12.1, FB2.2, JP1.1 (A), R3.1, U1.27 (DVDD)
GND: C1.2, C2.2, C3.2, C4.2, C5.2, C6.2, C7.2, C8.2, C9.2, C10.2, C11.2, C12.2, C13.2, C14.2, J1.17, J1.18, J2.2 (Ext), J3.2 (Ext), J4.1, JP1.3 (B), R1.2, R2.2, R4.2, R5.2, R6.2, R8.2, TP3.1, TR1.1, TR1.5, U1.16 (REFLO), U1.20 (AGND), U1.26 (DGND)
unnamed: C4.1, D1.2 (A), FB2.1, J1.16, JP3.2 (B)
unnamed: D1.1 (K), R8.1
unnamed: J1.1, JP2.1 (A), TP4.1, U1.28 (CLK)
unnamed: J1.2, U1.1 (D13)
unnamed: J1.3, U1.2 (D12)
unnamed: J1.4, U1.3 (D11)
unnamed: J1.5, U1.4 (D10)
unnamed: J1.6, U1.5 (D9)
unnamed: J1.7, U1.6 (D8)
unnamed: J1.8, U1.7 (D7)
unnamed: J1.9, U1.8 (D6)
unnamed: J1.10, U1.9 (D5)
unnamed: J1.11, U1.10 (D4)
unnamed: J1.12, U1.11 (D3)
unnamed: J1.13, U1.12 (D2)
unnamed: J1.14, U1.13 (D1)
unnamed: J1.15, U1.14 (D0)
unnamed: J2.1 (In), JP2.2 (B), R1.1
unnamed: J3.1 (In), TR1.3
unnamed: C5.1, FB1.1, J4.2, JP3.1 (A)
unnamed: JP1.2 (C), U1.25 (MODE)
unnamed: R5.1, U1.18 (FS_ADJ)
unnamed: C3.1, R2.1, R7.1, TP1.1, TR1.4, U1.22 (IOUTA)
unnamed: C2.1, R6.1, R7.2, TP2.1, TR1.6, U1.21 (IOUTB)
unnamed: C1.1, U1.17 (REFIO)
unnamed: R3.2, R4.1, U1.15 (SLEEP)

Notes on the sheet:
fmin=70kHz
Vout
EXT CLK
DVDD=Sleep GND=Active
Iout+
Close to connect AVDD and DVDD
+3.3V
GND=2's Complement DVDD=Unsigned binary
GND
Iout-
Must bend legs
50 Ohms

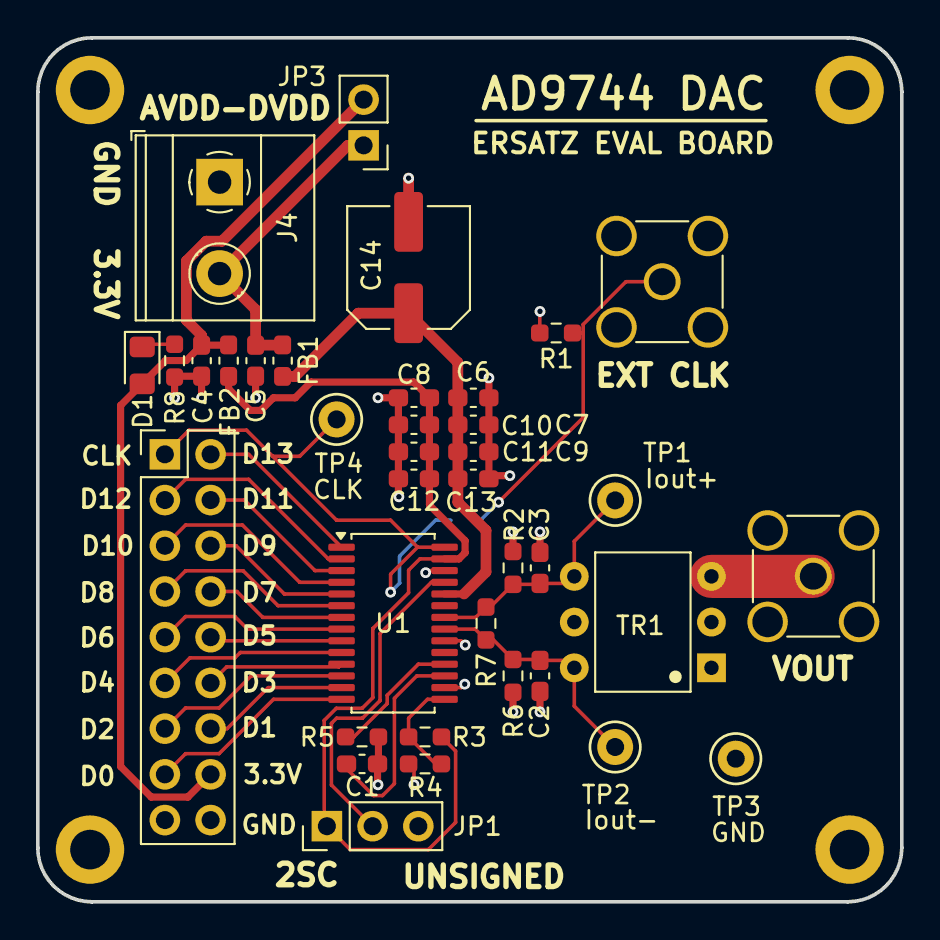
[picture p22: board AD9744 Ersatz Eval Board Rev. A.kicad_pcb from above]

Board: 2 copper layers, 48.0 x 48.0 mm, 42 parts (1 on the bottom side), 29 nets.

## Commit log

2025-01-01 Add BOM
    [AD9744 Ersatz Eval Board Rev.- BOM.csv]
2025-01-01 Update and rename AD9744 Ersatz Eval Board Rev.- BOM.csv to AD9744 Ersatz Eval Board Rev.A BOM.csv
    [AD9744 Ersatz Eval Board Rev.A BOM.csv]
2025-01-01 Update AD9744 Ersatz Eval Board Rev.A BOM.csv
    Updates to file name
2025-01-01 added Document dir
    [AD9744 Ersatz Eval Board Rev.A BOM.csv]
2025-01-01 added schematic
2025-01-01 updated schematic
2025-01-01 added gerbers
    [AD9744 Ersatz Eval Board Rev. A-B_Cu.gbl, AD9744 Ersatz Eval Board Rev. A-B_Mask.gbs, AD9744 Ersatz Eval Board Rev. A-B_Paste.gbp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]
2025-01-01 BOM update
    [AD9744 Ersatz Eval Board Rev.A BOM.csv]
2025-01-01 fixed BOM .CSV formatting
    [AD9744 Ersatz Eval Board Rev.A BOM.csv]
2025-01-01 bom changes
    [AD9744 Ersatz Eval Board Rev. A BOM.csv, AD9744 Ersatz Eval Board Rev.A BOM.csv]
2025-01-01 bom line changes
    [AD9744 Ersatz Eval Board Rev. A BOM.csv]
2025-01-02 Update AD9744 Ersatz Eval Board Rev. A BOM.csv
    [AD9744 Ersatz Eval Board Rev. A BOM.csv]
2025-01-02 updates to ref des on schema
2025-01-02 Create Assembly and User Guide
2025-01-02 Rename Assembly and User Guide to AD9744 Ersatz Eval Board Rev. AAssembly and User Guide
2025-01-02 Rename AD9744 Ersatz Eval Board Rev. AAssembly and User Guide to AD9744 Ersatz Eval Board Rev. A Assembly and User Guide
2025-01-02 Rename AD9744 Ersatz Eval Board Rev. A Assembly and User Guide to AD9744 Ersatz Eval Board Rev. A Assembly and User Guide.md
2025-01-02 Update AD9744 Ersatz Eval Board Rev. A Assembly and User Guide.md
2025-01-03 TR1 pad changes
    [AD9744 Ersatz Eval Board Rev. A-B_Cu.gbl, AD9744 Ersatz Eval Board Rev. A-B_Mask.gbs, AD9744 Ersatz Eval Board Rev. A-B_Paste.gbp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]
2025-01-03 new TR1 footprint
2025-01-03 changes for TR1
    [AD9744 Ersatz Eval Board Rev. A BOM.csv]
2025-01-04 tr1 footprint change
2025-01-04 TR1 silkscreen change
    [AD9744 Ersatz Eval Board Rev. A-B_Cu.gbl, AD9744 Ersatz Eval Board Rev. A-B_Mask.gbs, AD9744 Ersatz Eval Board Rev. A-B_Paste.gbp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]
2025-01-04 Update and rename AD9744 Ersatz Eval Board Rev. A Assembly and User Guide.md to AD9744 Ersatz Eval Board Rev. A User Guide.md
2025-01-04 Update AD9744 Ersatz Eval Board Rev. A User Guide.md
2025-01-05 Rename AD9744 Ersatz Eval Board Rev. A Back Copper.png to AD9744 Ersatz Eval Board Rev. A Copper Back.png
2025-01-05 Rename AD9744 Ersatz Eval Board Rev. A Front Copper.png to AD9744 Ersatz Eval Board Rev. A Copper Front.png
2025-01-05 Rename AD9744 Ersatz Eval Board Rev. A Front.png to AD9744 Ersatz Eval Board Rev. A Layout Front.png
2025-01-05 Rename AD9744 Ersatz Eval Board Rev. A Back.png to AD9744 Ersatz Eval Board Rev. A Layout Back.png
2025-01-05 Update AD9744 Ersatz Eval Board Rev. A Interfaces.png
2025-01-05 Update AD9744 Ersatz Eval Board Rev. A 3D Render Front.png
2025-01-05 fixed schema links
    [AD9744 Ersatz Eval Board Rev. A-B_Cu.gbl, AD9744 Ersatz Eval Board Rev. A-B_Mask.gbs, AD9744 Ersatz Eval Board Rev. A-B_Paste.gbp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]
2025-01-05 zip gerbers
    [AD9744 Ersatz Eval Board Rev. A-B_Cu.gbl, AD9744 Ersatz Eval Board Rev. A-B_Mask.gbs, AD9744 Ersatz Eval Board Rev. A-B_Paste.gbp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]
2025-01-05 added kicad files
    [AD9744 Ersatz Eval Board Rev. A-B_Cu.gbl, AD9744 Ersatz Eval Board Rev. A-B_Mask.gbs, AD9744 Ersatz Eval Board Rev. A-B_Paste.gbp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]
2025-01-06 new render
    [AD9744 Ersatz Eval Board Rev. A.kicad_pcb]
2025-01-06 kicad checks
2025-01-07 fixed LED color
2025-01-07 fixed error in schema note
    [AD9744 Ersatz Eval Board Rev. A.kicad_sch]
2025-01-17 clean up
    [AD9744 Ersatz Eval Board Rev. A.kicad_pcb, AD9744 Ersatz Eval Board Rev. A.kicad_sch]
2025-01-17 Create AD9744 Ersatz Eval Board Rev. A 13.12MHz tone.png
2025-01-17 Release A1
    [AD9744 Ersatz Eval Board Rev. A BOM.csv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]
2025-02-08 Create AD9744 Ersatz Board Rev. A SN1.png
2025-02-08 Update AD9744 Ersatz Eval Board Rev. A SN1.jpg
